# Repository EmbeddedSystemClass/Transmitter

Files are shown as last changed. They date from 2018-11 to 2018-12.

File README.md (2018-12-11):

# ZJUNlict Transmitter Description

The transmitter contains the interface to PC using virtual serial port [CP2102](https://www.silabs.com/documents/public/data-sheets/CP2102-9.pdf), [core board](https://github.com/ZJUNlict/Core_Board) and two [nRF2401A](https://www.nordicsemi.com/eng/Products/2.4GHz-RF/nRF2401A) modules. (The board is designed using [Altium Designer](https://www.altium.com/altium-designer/) 17.1)

The 2D and 3D design views are shown below:

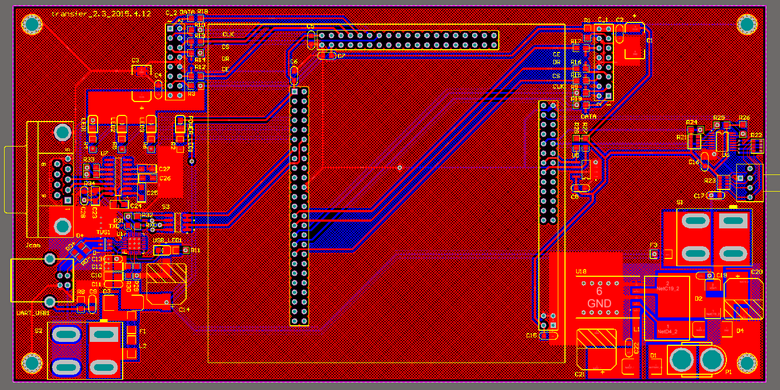
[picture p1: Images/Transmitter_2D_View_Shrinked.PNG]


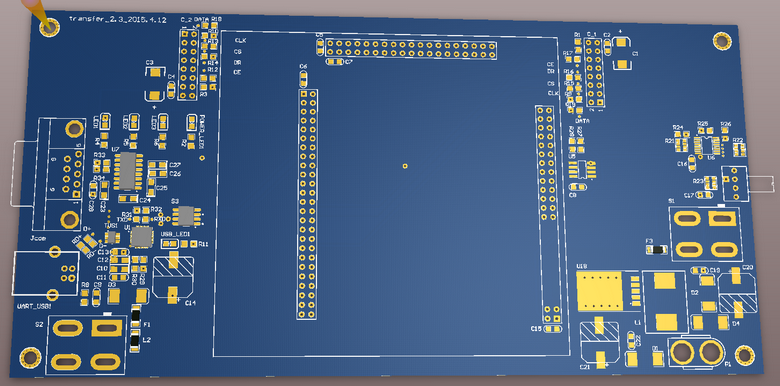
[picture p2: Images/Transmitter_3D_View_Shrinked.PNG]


The main features are:

* Support traditional RS232 DB9 interface (MAX3232) and USB virtual serial port interface based on [CP2102](https://www.silabs.com/documents/public/data-sheets/CP2102-9.pdf). FPGA firmware can be found in corresponding [firmware repository](https://github.com/ZJUNlict/Firmware_for_Transmitter).
* Two connectors for nRF2401A modules.
* I/O expander (PCA9557PW) and rotary DIP switch (A6R/A6RV) for easier transmitter frequency set.
* Support both USB and battery power supply

The photo of the transmitter board is shown below as references. 

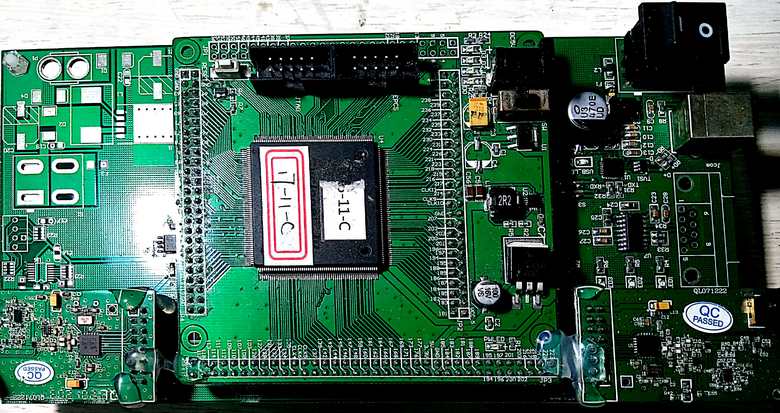
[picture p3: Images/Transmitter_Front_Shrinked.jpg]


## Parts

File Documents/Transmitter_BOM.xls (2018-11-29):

No. | Name | Code | Spec | Designator | Brand | Package | Quantity | Unit | Attribute | Remark
 | UART - USB Chip | cp2102-GM |  | U1 |  | QFN-28 | 1
 | LED |  | 1.7V,0805,Red | LED1、2、3、POWER_LED1、USB_LED1 |  | 0805D | 5
 | Resistor |  | 1k 5% | R1, R2, R3, R4, R5, R6, R11, R26 |  | 0805R | 8
 | Resistor |  | 1M 5% | R8 |  | 0805R | 1
 | Resistor |  | 22 5% | R9, R10, R12, R13, R14, R15, R16, R17, R18, R19,R29, R30, R31, R32, R33, R34, RD+, RD- |  | 0805R | 18 |  | .
 | Fuse |  | 500mA PPTC | F1,F3 |  | 1206 | 2
 | 4P SMT Switch |  |  | S3 |  | SO8_M | 1
 | Inductance |  |  | L2 |  | 1206 | 1
 | Electrolytic Capacitor |  | 25V 470uf 10*10,-55to+105℃ | C14,C20,C21 |  | J10 | 3
 | Tantalum capacitor |  | 47u 20V 10% -55to125℃ ESR=100mOhms 73mm*43mm | C1, C3 |  | 7343c/d | 2
 | Ceramic Cap |  | 0.1uf,±10%，50V，-55to+125℃, | C2, C4, C5, C6, C7,C8 C9,C11, C13,C15,C16,C17,C19,C22,C28 |  | 0805C | 15
 | Ceramic Cap |  | 1uf,±10%，50V， -55to+125℃ | C24,C25,C26,C27 |  | CAP-3216 | 4
 | Tantalum capacitor |  | 1uf | C10,C23 |  | CAP-3216 | 2
 | Tantalum capacitor |  | 4.7uf | C12 |  | CAP-3216 | 1
 | Resistor |  | 10k 1% | R27,R28 |  | 0805R | 2
 | Resistor |  | 1.6k 1% | R24,R25 |  | 0805R | 2
 | USB Connector | 1001BR-04-WH |  | UART_USB1 | SHPEAK | USB-B | 1
 | nRF Connetor | 203S-3C-2X8P-8.5/3.0 |  | C_1, C_2 | SHPEAK | HDR2X8 | 2
 | Connector | 203S-3C-2X25P-8.5/3.0 |  | 1 | SHPEAK
 | Connector | 203S-3C-2X19P-8.5/3.0 |  | 1 | SHPEAK
 | Connector | 203S-3C-2X13P-8.5/3.0 |  | 1 | SHPEAK
 | Connector | 203S-3C-2X2P-8.5/3.0 |  | 1 | SHPEAK
 | nRF Module | nrf2401A |  |  |  |  | 2
 | Core Board | EP3C25 |  |  | ALTERA |  | 1
 | Rotatry DIP Switch | A6RV-161RF |  | P28 | CHAU-HUA | A6RV-161RS | 1
 | Resisters Packs |  | 10K 1% | R23 |  | 0603 Resister Pack | 1
 | Resisters Packs |  | 2K 1% | R21 |  | 0603 Resister Pack | 1
 | Resisters Packs |  | 22 1% | R22 |  | 0603 Resister Pack | 1
 | IC | PCA9557PW |  | U6 |  | TSSOP16 | 1
 | IC | MAX3232CSE | 3.0V TO 5.5V, Low-Power, up to 1Mbps, True RS-232 Transceiver Using Four 0.1 External Capacitor | U7 |  | NSO16_M | 1
 | IC | LM2576D2T-005G |  | U18 |  | D2PAK | 1
 | IC | AT24C08B-SH |  | U5 | Atmel | SO-G8 | 1
 | Rocket Switch | A8L-21-11N2 |  | S1,S2 | OMRON | A8L-21-11N2 | 2
 | Diode |  | SS36，60V,3A | D1, D2,D3,D4 |  | DO-214AB | 4
 | Inductance | MSS1260T-100uH |  | L1 | Coilcraft | L | 1
 | Connector | SPT1.5/4-H-3.5 |  | P5 | Phoenix | SPT1.5-4P-H-3.5 | 1
 | RS-232 DB9 Connector |  |  | Jcom |  | DSUB1.385-2H9 | 1
 | IC | TVS |  | TVS1 |  | SOT23-6_M | 1

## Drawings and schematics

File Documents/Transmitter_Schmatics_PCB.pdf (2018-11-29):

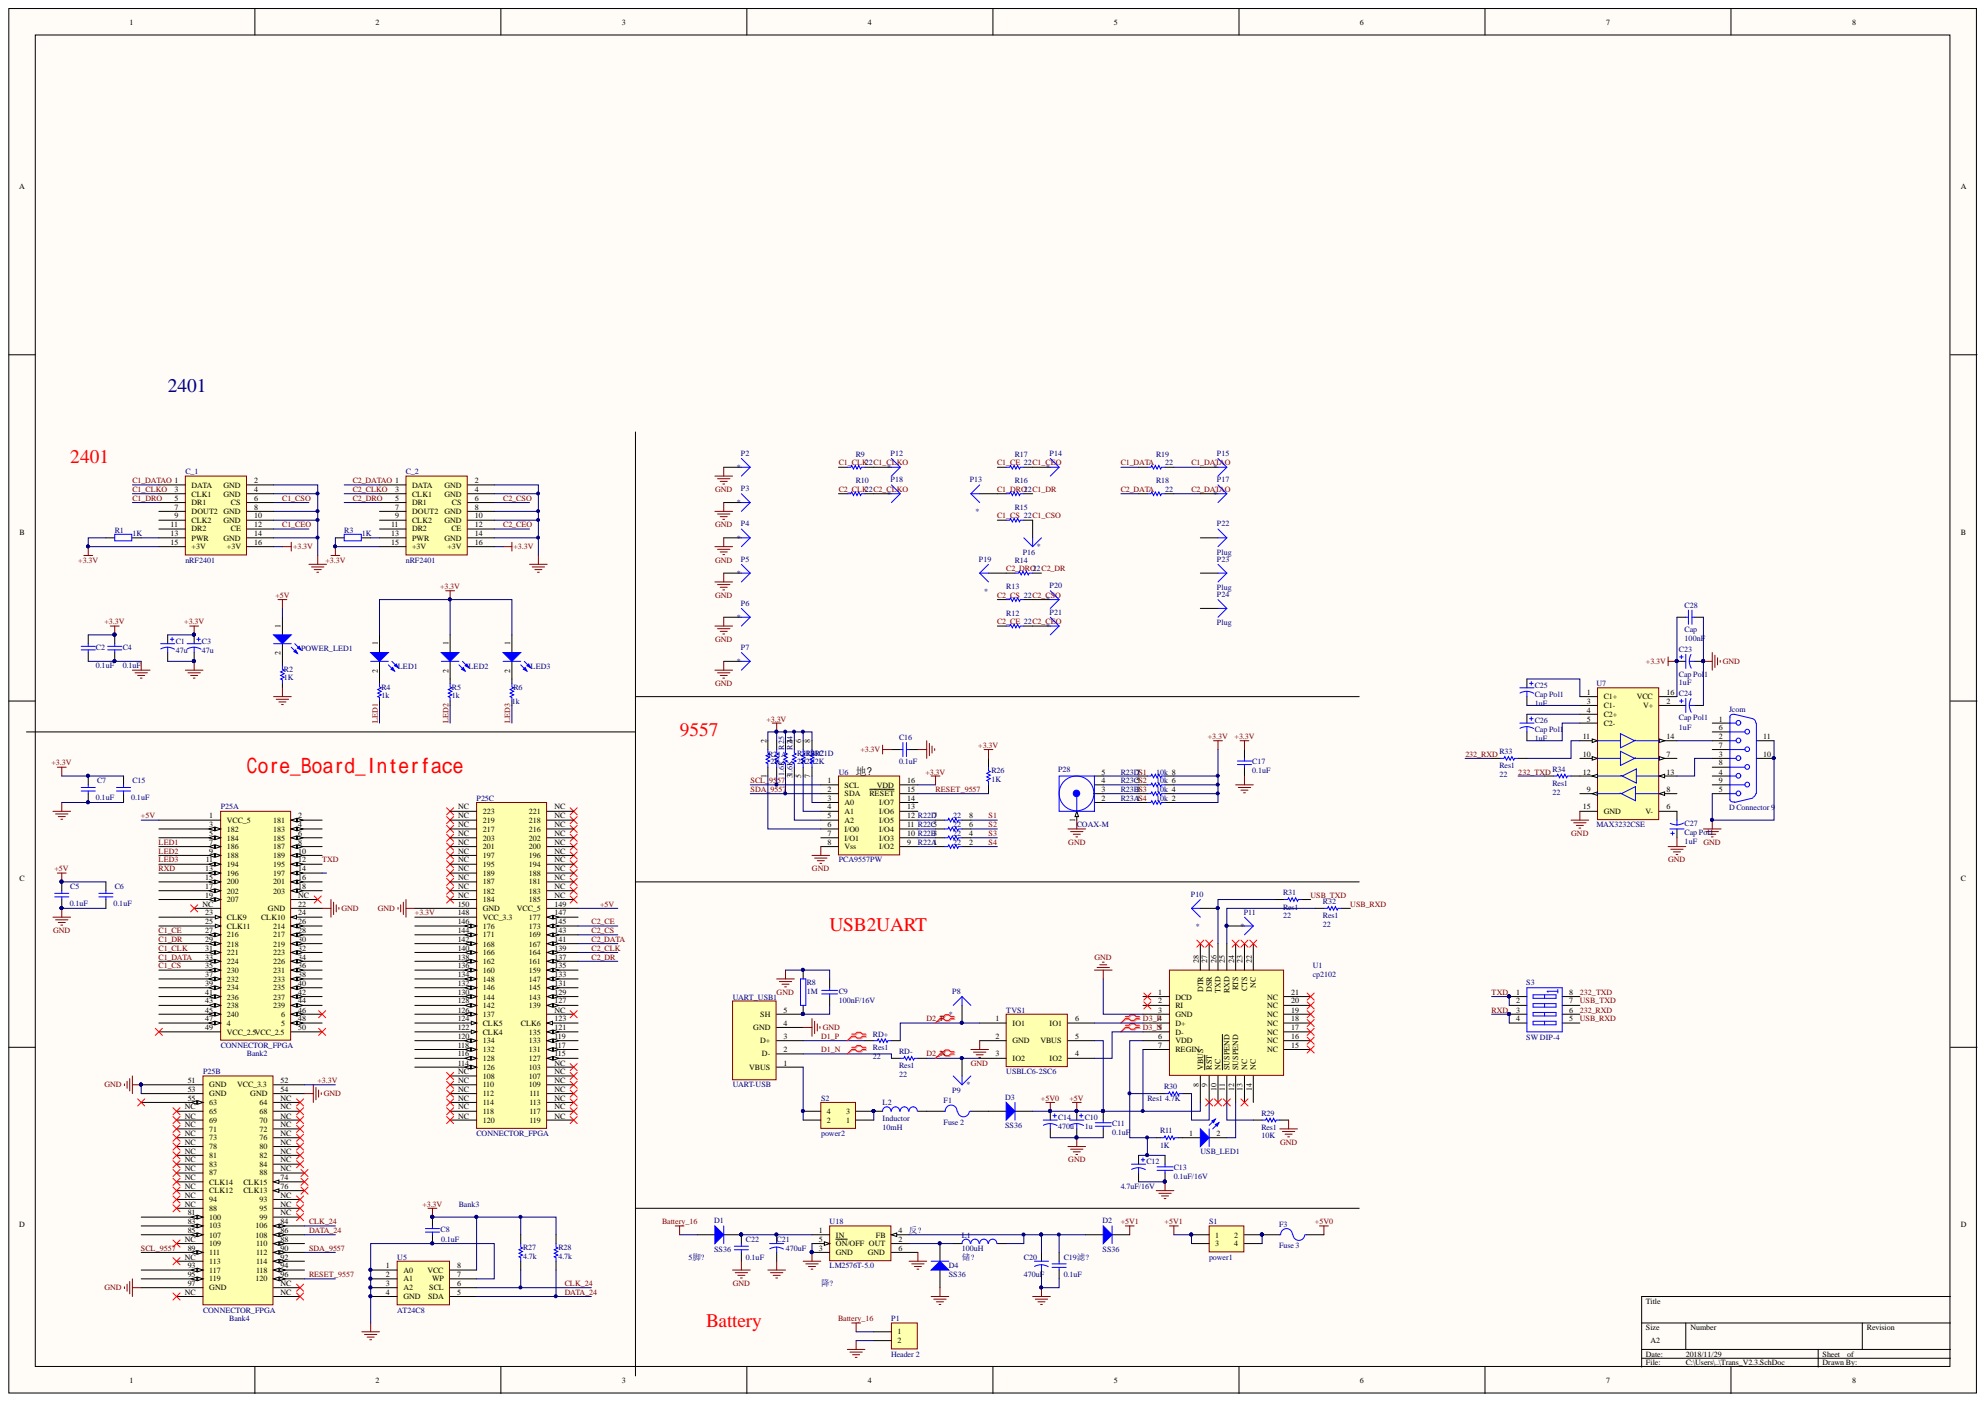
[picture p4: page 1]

7 | 7 3 | D Connector 9 | 10

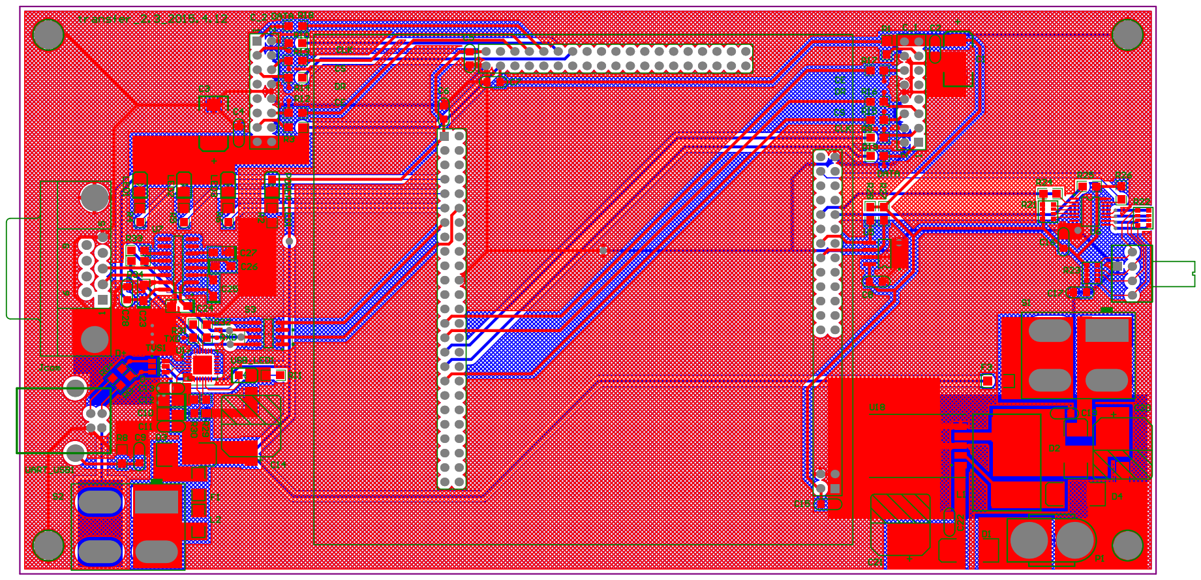
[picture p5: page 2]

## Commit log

2018-11-19 Add PCB files
    [Trans_V2.3.PcbDoc, Trans_V2.3.PrjPCB, Trans_V2.3.SchDoc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]
2018-11-29 Add transmitter bom and readme
    [Trans_V2.3.PcbDoc, Trans_V2.3.PrjPCB]
